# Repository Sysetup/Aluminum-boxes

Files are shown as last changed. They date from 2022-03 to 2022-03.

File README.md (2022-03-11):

```console
   ____             __             
  / __/_ _____ ___ / /___ _____ _/|
 _\ \/ // (_-</ -_) __/ // / _ > _<
/___/\_, /___/\__/\__/\_,_/ .__//  
    /___/                /_/       
> Systems development company.
```

- [Boxes.](#boxes)

# Boxes.

1. Boxes may be stacked with each other and join the internal space between them.
2. **Each box** shall have on its exterior a part that allows it to be assembled on any of its sides with another box of the same size or of other sizes, all the boxes shall have harmonious measurements so that they can be assembled together to form figures between them, they shall therefore have a part that allows them to be assembled with another box and can be secured in such a way that only with a key or by opening a padlock can they be disassembled.
3. **Each box** shall have perforations that allow it to be assembled on the floor, on a wall or on the ceiling. On the floor, walls or ceiling there shall be a part assembled with deep holes in the concrete that will allow the drawer(s) to be assembled and secured with padlocks, so that they cannot be moved by anyone but the owner of the padlocks.
4. **Each box** shall be capable of being locked with a key, key or padlock, so that it cannot be opened by anyone but the owner.
5. Aluminium material or (similar in weight, more economical and equal or superior in strength to aluminium).

----

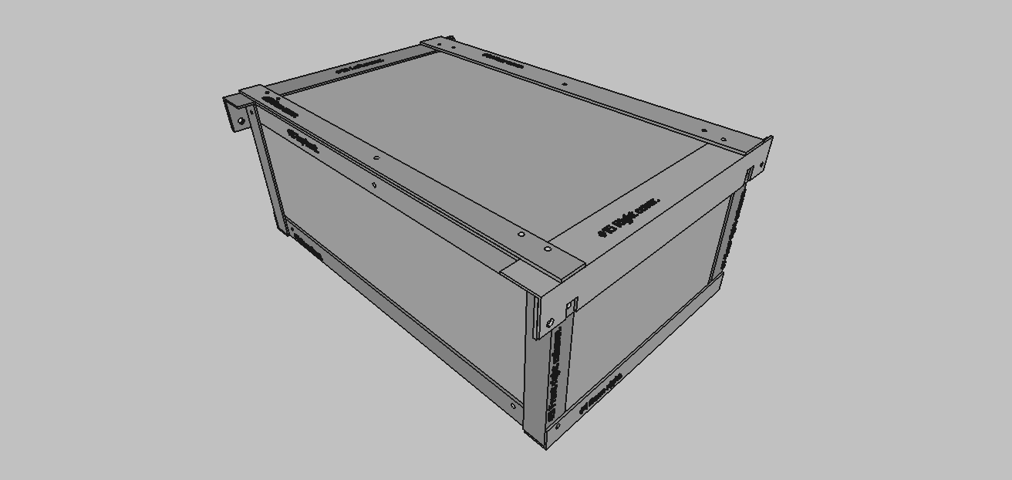
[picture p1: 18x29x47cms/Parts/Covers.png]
Covers


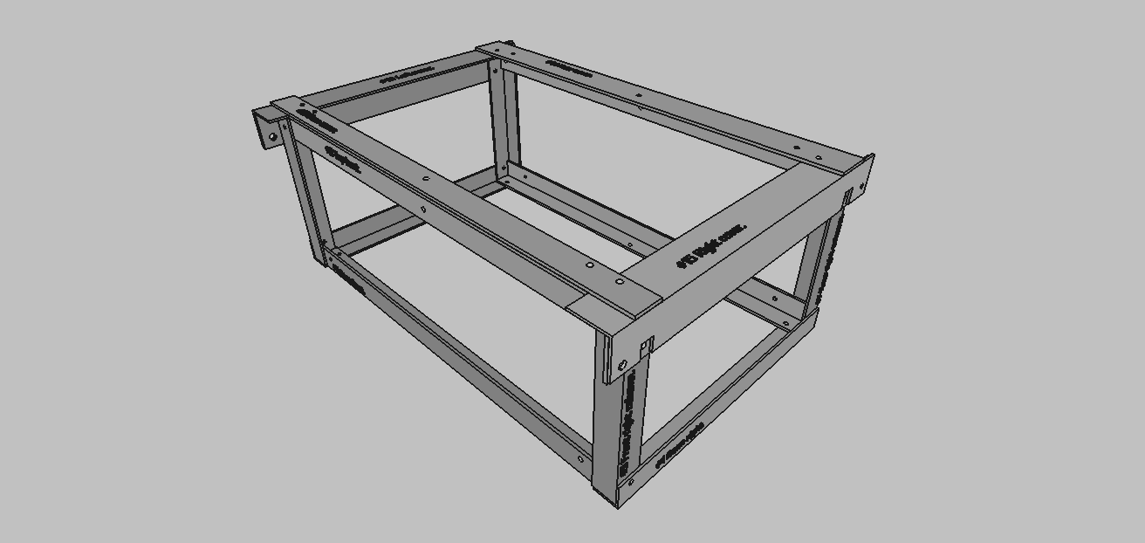
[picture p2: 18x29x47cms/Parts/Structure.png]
Structure


----

1. [Box: 180 x 290 x 470 mm.](./18x29x47cms/180x290x470mm.md)
2. [Box: 290 x 290 x 470 mm.](./29x29x47cms/290x290x470mm.md)
3. [Box: 290 x 470 x 470 mm.](./29x47x47cms/290x470x470mm.md)
4. [Box: 290 x 470 x 760 mm.](./29x47x76cms/290x470x760mm.md)

----

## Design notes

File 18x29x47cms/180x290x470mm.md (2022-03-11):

```console
   ____             __             
  / __/_ _____ ___ / /___ _____ _/|
 _\ \/ // (_-</ -_) __/ // / _ > _<
/___/\_, /___/\__/\__/\_,_/ .__//  
    /___/                /_/       
> Systems development company.
```

- [Box: 180 x 290 x 470 mm:](#box-180-x-290-x-470-mm)
  - [Box dimensions:](#box-dimensions)
  - [Parts:](#parts)
    - [Aluminium angles:](#aluminium-angles)
      - [Part no: A011.](#part-no-a011)
        - [Quantities:](#quantities)
      - [Reference: PA019.](#reference-pa019)
        - [Quantities:](#quantities-1)
    - [Aluminium plates:](#aluminium-plates)
      - [Part no: P18.](#part-no-p18)
        - [Quantities:](#quantities-2)
      - [Reference: PP030.](#reference-pp030)
        - [Quantities:](#quantities-3)
    - [Screws:](#screws)
    - [Nuts:](#nuts)
    - [Washers:](#washers)
    - [Cover:](#cover)
      - [Covering with carpet:](#covering-with-carpet)
      - [Covering measurements:](#covering-measurements)
      - [Cover with PP030 plates:](#cover-with-pp030-plates)

# Box: 180 x 290 x 470 mm:

## Box dimensions:

1. Box dimensions: 18 x 29 x 29 x 47 cms (180 x 290 x 470 mm), internally. Using fibonasi sequence measurements with seeds 1 and 3.

## Parts:

### Aluminium angles:

#### Part no: A011.
   
1. External width: 25.15 mm.
2. Internal width: 22,85 mm.
3. Calibre: 2.3 mm.

##### Quantities:

1. 2 * 470.00 mm --> Rear base length and front base length. [Parts #3 and #4] 
2. 2 * 300.94 mm --> Base widths.  [Parts #1 and #2] 3. 
3. 4 * 182.30 mm --> Rear and front columns. [(#5 and #6), (#7 and #8)].

Total angles A011: 2271.08 mm. **2.3 Metres.

#### Reference: PA019.
   
1. External width: 38.5 mm.
2. Internal width: 38,1 mm.
3. Calibre: 3.18 mm.

##### Quantities:

1. 2 * 342 mm --> Cover widths. [Parts #15 and #16] 

Total angles PA019: 683.8 mm. **70 Centimetres.

### Aluminium plates:

#### Part no: P18.

Width: 25,65 mm.
2. Gauge: 3.17 mm.

##### Quantities:
      
1. 2 * 470 mm --> Length top front and top rear. 470 mm. [#9 y #10]
2. 1 * 486,9 mm --> Length front top. [#13]
3. 2 * 410,20 mm--> Lid support bases. [#17 y #18]

Total plates P18: 2247.3 mm. 2.3 Meter ** 2.3 Meter ** 2.3 Meter ** 2.3 Meter ** 2.3 Meter

#### Reference: PP030.
   
Width 38.1 mm.
2. Gauge: 3.17.

##### Quantities:

1. 2 * 342 mm --> Width top right and top left. 642 mm. [#11 y #12]
2. 1 * 486,9 mm --> Length rear cover [#14].

Total plates PP030: 1128,9 mm. 1.2 Meters ** 1.2 Meters ** 1.2 Meters

### Screws:

1. 36 pcs. 4,8 mm diameter. 17 mm long thread. (4 of 8 mm) (The minimum that they must have to cover the thickness of 2 corners and a plate that are the 3 parts of the door that need more length. For the purchased ones you have to cut them) Head diameter 9 mm. 3 mm head height, 34 mm total length.

### Nuts:

1. 36 pcs. nuts with security. 10.9 mm diameter at longest end, 3.9 mm diameter inner hole, width (gauge) 6 mm.

### Washers:

1. 72 pcs.
2. 12.8 mm diameter, 5.5 mm hole, gauge 1 mm.

### Cover:

#### Covering with carpet:

1. Area: 0,55 mts² = cms²/10000 -> 0.5462 meters² ≃ 60 cms². Thickness: 3 mm. 
2. [Reference calculation](https://www.calculator.net/surface-area-calculator.html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)

#### Covering measurements:

1. Top cover: 441,00 mm x 272,00 mm x max: 3 mm.
2. Bottom cover: 460 mm x 282,00 mm x maximum: 3 mm.
3. Front cover: 462,00 mm x 167,00 mm x max. 3 mm.
4. Rear cover: 462,60 mm x 167,00 mm x max. 3 mm.
5. Right cover: 282,00 mm x 155,00 mm x maximum: 3 mm.
6. Left cover: 282.00 mm x 155.00 mm x max. 3 mm.

#### Cover with PP030 plates:

1. 7 x 486.9 mm. Top.
2. 4 x 470 mm. Front.
3. 3 x 470 mm. Rear.
4. 6 x 470 mm. Bottom.
5. 6 x 300 mm. Right and Left.

Total: 9175.3 mm. **9.2 metres** $9800 each metre.

----

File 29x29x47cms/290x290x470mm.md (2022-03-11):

```console
   ____             __             
  / __/_ _____ ___ / /___ _____ _/|
 _\ \/ // (_-</ -_) __/ // / _ > _<
/___/\_, /___/\__/\__/\_,_/ .__//  
    /___/                /_/       
> Systems development company.
```

- [Box: 290 x 290 x 470 mm.](#box-290-x-290-x-470-mm)
  - [Box dimensions:](#box-dimensions)
  - [Parts:](#parts)
    - [Aluminium angles:](#aluminium-angles)
      - [Part no: A011.](#part-no-a011)
        - [Quantities:](#quantities)
      - [Reference: PA019.](#reference-pa019)
        - [Quantities:](#quantities-1)
    - [Aluminium plates:](#aluminium-plates)
      - [Part no: P18.](#part-no-p18)
        - [Quantities:](#quantities-2)
      - [Reference: PP030.](#reference-pp030)
        - [Quantities:](#quantities-3)
    - [Screws:](#screws)
    - [Nuts:](#nuts)
    - [Washers:](#washers)
    - [Cover:](#cover)
      - [Covering with pin:](#covering-with-pin)
      - [Measurements coverings:](#measurements-coverings)

# Box: 290 x 290 x 470 mm.

## Box dimensions:

1. Box dimensions: 29 x 29 x 47 cms (290 x 290 x 470 mm), internally. Using fibonasi sequence measurements with seeds 1 and 3.

## Parts:

### Aluminium angles:

#### Part no: A011.
   
1. External width: 25.15 mm.
2. Internal width: 22,85 mm.
3. Calibre: 2.3 mm.

##### Quantities:

1. 2 * 470.00 mm --> Rear base length and front base length. [Parts #3 and #4] 
2. 2 * 300.94 mm --> Base widths.  [Parts #1 and #2] 3. 
3. 4 * 292.30 mm --> Rear and front columns. [(#5 and #6), (#7 and #8)].

Total angles A011: 2271.08 mm. **2.74 Metres.

#### Reference: PA019.
   
1. External width: 38.5 mm.
2. Internal width: 38,1 mm.
3. Calibre: 3.18 mm.

##### Quantities: 

1. 2 * 342 mm --> Cover widths. [Parts #15 and #16]

Total angles PA019: 683.8 mm. **70 Centimetres.

### Aluminium plates:

#### Part no: P18.

Width: 25,65 mm.
2. Gauge: 3.17 mm.

##### Quantities:
      
1. 2 * 470 mm --> Length top front and top rear. 470 mm. [#9 y #10] 
2. 1 * 486,9 mm --> Length front top. [#13]
3. 2 * 410,20 mm--> Lid support bases. [#17 y #18]

Total plates P18: 2247.3 mm. 2.3 Meter ** 2.3 Meter ** 2.3 Meter ** 2.3 Meter ** 2.3 Meter

#### Reference: PP030.
   
Width 38.1 mm.
2. Gauge: 3.17.

##### Quantities:

1. 2 * 342 mm --> Width top right and top left. 642 mm. [#11 y #12]
2. 1 * 486,9 mm --> Length rear cover [#14].

Total plates PP030: 1128,9 mm. 1.2 Meters ** 1.2 Meters ** 1.2 Meters

### Screws:

1. 27 pcs. 4,8 mm diameter. 17 mm long thread. (4 of 8 mm) (The minimum that they must have to cover the thickness of 2 corners and a plate that are the 3 parts of the door that need more length. For the purchased ones you have to cut them) Head diameter 9 mm. 3 mm head height, 34 mm total length.

### Nuts:

1. 27 pcs nuts with security. 10.9 mm diameter at longest end, 3.9 mm diameter inner hole, width (gauge) 6 mm.

### Washers:

1. 54 pcs.
2. 12.8 mm diameter, 5.5 mm hole, gauge 1 mm.

### Cover:

#### Covering with pin:

1. Area: 0.7134 meters² ≃ 72 cms². Thickness: 2mm.
2. [Calculation reference](https://www.calculator.net/surface-area-calculator.html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)

#### Measurements coverings:

1. Top cover: 441,00 mm x 272,00 mm x max: 3 mm.
2. Bottom cover: 460 mm x 282,00 mm x maximum: 3 mm.
3. Front cover: 462,00 mm x 273,00 mm x max. 3 mm.
4. Rear cover: 462,60 mm x 273,00 mm x max. 3 mm.
5. Right cover: 282,00 mm x 265,00 mm x maximum: 3 mm.
6. Left cover: 282,00 mm x 265,00 mm x max. 3 mm.

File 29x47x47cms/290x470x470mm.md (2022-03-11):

```console
   ____             __             
  / __/_ _____ ___ / /___ _____ _/|
 _\ \/ // (_-</ -_) __/ // / _ > _<
/___/\_, /___/\__/\__/\_,_/ .__//  
    /___/                /_/       
> Systems development company.
```

- [Box: 290 x 470 x 470 mm:](#box-290-x-470-x-470-mm)
  - [Box dimensions:](#box-dimensions)
  - [Parts:](#parts)
    - [Angles:](#angles)
      - [Reference: A15:](#reference-a15)
        - [Quantities:](#quantities)
      - [Reference: PA019:](#reference-pa019)
        - [Quantities:](#quantities-1)
    - [Plates:](#plates)
      - [Part no: PP030:](#part-no-pp030)
        - [Quantities:](#quantities-2)
    - [Covering:](#covering)
      - [Covering with carpet:](#covering-with-carpet)
      - [Cover measurements:](#cover-measurements)

# Box: 290 x 470 x 470 mm:

## Box dimensions:

1. Box dimensions: 29 x 47 x 47 cms (290 x 470 x 470 x 470 mm), internally. Using fibonasi sequence measurements with seeds 1 and 3.

## Parts:

### Angles:

#### Reference: A15:

1. External width: 31.9 mm.
2. Internal width: 28.9 mm.
3. Gauge: 3.1 mm.

##### Quantities:

1. 2 * 470 mm --> Rear base length and front base length. [Parts #3 and #4]
2. 2 * 482.4 mm --> Base widths.  [Parts #1 and #2] 3.
3. 4 * 293.10 mm --> Rear and front columns. [(#5 and #6), (#7 and #8)].

Total angles A015: 3077.2 mm. **3,1 Metres.

#### Reference: PA019:

1. External width: 38,5 mm.
2. Internal width: 35,1 mm.
3. Calibre: 3.18 mm.

##### Quantities: 

1. 2 * 550 --> Cap widths. [Parts #15 and #16]

Total angles PA019: 1100 mm. **1.3 Meters

### Plates:

#### Part no: PP030:
   
1. Width 38,1 mm.
2. Calibre: 3.17.

##### Quantities:

1. 2 * 550 mm --> Width top right and top left. 1004.8 mm. [#11 y #12] 
2. 2 * 568 mm --> Length top front and rear. 1556 mm. [#13 y #14]
3. 2 * 470 mm --> Length top front and top rear. 1520 mm. [#9 y #10]

Total PP030 plates: 3176 mm. **3.3 Metres.

### Covering:

#### Covering with carpet:

1. Area: 0.55 mts² = cms²/10000 -> 0.5462 meters² ≃ 60 cms². Thickness: 3 mm. 
2. [Reference calculation](https://www.calculator.net/surface-area-calculator.html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)

#### Cover measurements:

1. Top cover: 440 mm x 440 mm x max: 3 mm.
2. Bottom cover: 445 mm x 445 mm x maximum: 3 mm.
3. Front cover: 465 mm x 280 mm x max.: 3 mm.
4. Rear cover: 465 mm x 265 mm x max.: 3 mm.
5. Right cover: 465 mm x 275 mm x max. 3 mm.
6. Left cover: 465 mm x 275 mm x max. 3 mm.

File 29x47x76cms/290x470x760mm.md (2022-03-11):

```console
   ____             __             
  / __/_ _____ ___ / /___ _____ _/|
 _\ \/ // (_-</ -_) __/ // / _ > _<
/___/\_, /___/\__/\__/\_,_/ .__//  
    /___/                /_/       
> Systems development company.
```

- [Box: 290 x 470 x 760 mm:](#box-290-x-470-x-760-mm)
  - [Box dimensions:](#box-dimensions)
  - [Parts:](#parts)
    - [Angles:](#angles)
      - [Reference: A15:](#reference-a15)
        - [Quantities:](#quantities)
      - [Reference: PA019:](#reference-pa019)
        - [Quantities:](#quantities-1)
    - [Plates:](#plates)
      - [Part no: PP030:](#part-no-pp030)
        - [Quantities:](#quantities-2)
    - [Screws:](#screws)
    - [Nuts:](#nuts)
    - [Washers:](#washers)
    - [Cover:](#cover)
      - [Covering with carpet:](#covering-with-carpet)
      - [Measurements coverings:](#measurements-coverings)

# Box: 290 x 470 x 760 mm:

## Box dimensions:

1. Box Dimensions: 29 x 47 x 76 cms (290 x 470 x 760 mm), internally. Using fibonasi sequence measurements with seeds 1 and 3.

## Parts:

### Angles:

#### Reference: A15:

1. External width: 31.9 mm.
2. Internal width: 28.9 mm.
3. Gauge: 3.1 mm.

##### Quantities:

1. 2 * 760 mm --> Rear base length and front base length. [Parts #3 and #4]
2. 2 * 482.4 mm --> Base widths.  [Parts #1 and #2] 3.
3. 4 * 293.10 mm --> Rear and front columns. [(#5 and #6), (#7 and #8)].

Total angles A015: 3658 mm. **4 Metres.

#### Reference: PA019:

1. External width: 38,5 mm.
2. Internal width: 35,1 mm.
3. Calibre: 3.18 mm.

##### Quantities: 

1. 2 * 550 --> Cap widths. [Parts #15 and #16]

Total angles PA019: 1100 mm. **1.2 Meters

### Plates:

#### Part no: PP030:
   
1. Width 38,1 mm.
2. Calibre: 3.17.

##### Quantities:

1. 2 * 550 mm --> Width top right and top left. 1004.8 mm. [#11 y #12]
2. 2 * 785 mm --> Length top front and rear. 1556 mm. [#13 y #14]
3. 2 * 760 mm --> Length top front and top rear. 1520 mm. [#9 y #10]

Total PP030 plates: 4190 mm. **4.2 Metres.

### Screws:

1. 42 pcs. 4,8 mm diameter. 17 mm long thread. (4 of 8 mm) (The minimum that they must have to cover the thickness of 2 corners and a plate that are the 3 parts of the door that need more length. For the purchased ones you have to cut them) Head diameter 9 mm. 3 mm head height.
2. Assembling the box physically, you can see that the screws can be 16 mm long on the thread alone.

### Nuts:

1. 42 units of nuts with security. 10.9 mm diameter at the longest end, 3.9 mm diameter inner hole, width (gauge) 6 mm.

### Washers:

1. 84 pcs.
2. 12.8 mm diameter, 5.5 mm hole, gauge 1 mm.

### Cover:

#### Covering with carpet:

1. Area: 1.4278 meters² ≃ 1.50 cms².  Thickness: 3 mm.
2. [Reference calculation](https://www.calculator.net/surface-area-calculator.html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)

#### Measurements coverings:

3. Top cover: 755 mm x 440 mm x max: 3 mm.
4. Bottom cover: 745 mm x 445 mm x max.: 3 mm.
5. Front cover: 745 mm x 280 mm x maximum: 3 mm.
6. Rear cover: 745 mm x 265 mm x maximum: 3 mm.
7. Right cover: 465 mm x 275 mm x max. 3 mm.
8. Left cover: 465 mm x 275 mm x max. 3 mm.

----

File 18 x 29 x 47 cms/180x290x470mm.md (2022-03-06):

```console
   ____             __             
  / __/_ _____ ___ / /___ _____ _/|
 _\ \/ // (_-</ -_) __/ // / _ > _<
/___/\_, /___/\__/\__/\_,_/ .__//  
    /___/                /_/       
> Systems development company.
```

- [Box: 180 x 290 x 470 mm:](#box-180-x-290-x-470-mm)
  - [Cajas a construir:](#cajas-a-construir)
  - [Medidas de la caja:](#medidas-de-la-caja)
  - [Partes:](#partes)
    - [Angulos de aluminio:](#angulos-de-aluminio)
      - [Referencia: A011.](#referencia-a011)
        - [Cantidades:](#cantidades)
      - [Referencia: PA019.](#referencia-pa019)
        - [Cantidades:](#cantidades-1)
    - [Platinas de aluminio:](#platinas-de-aluminio)
      - [Referencia: P18.](#referencia-p18)
        - [Cantidades:](#cantidades-2)
      - [Referencia: PP030.](#referencia-pp030)
        - [Cantidades:](#cantidades-3)
    - [Tornillos:](#tornillos)
    - [Tuercas:](#tuercas)
    - [Arandelas:](#arandelas)
    - [Cubrimiento:](#cubrimiento)
      - [Cubrimiento con alfajor:](#cubrimiento-con-alfajor)
      - [Medidas cubrimientos:](#medidas-cubrimientos)
      - [Cubrimiento con platinas PP030:](#cubrimiento-con-platinas-pp030)
  - [Costos totales:](#costos-totales)
    - [Costos angulos:](#costos-angulos)
    - [Costos platinas:](#costos-platinas)
    - [Costos tornillos:](#costos-tornillos)
    - [Costos tuercas:](#costos-tuercas)
    - [Costos arandelas:](#costos-arandelas)
    - [Costos cubiertas:](#costos-cubiertas)
      - [Cubierta con alfajor:](#cubierta-con-alfajor)
      - [Cubierta con lamina perforada:](#cubierta-con-lamina-perforada)
      - [Cubierta con maya:](#cubierta-con-maya)
    - [COSTO TOTAL: $120026 con alfajor.](#costo-total-120026-con-alfajor)
  - [Repositori:](#repositori)

# Box: 180 x 290 x 470 mm:

## Cajas a construir:

1. [x] Para elementos solares.
2. [x] Para papeleria.
3. [ ] Para alacena, comidas, cafe, leches, chocolate.
4. [ ] Para libros.

## Medidas de la caja:

1. Medidas de la caja: 18 x 29 x 47 cms (180 x 290 x 470 mm), internamente. Usando medidas de la secuencia fibonasi con semillas 1 y 3.

## Partes:

### Angulos de aluminio:

#### Referencia: A011.
   
1. Ancho externo: 25,15 mm.
2. Ancho interno: 22,85 mm.
3. Calibre: 2,3 mm.

##### Cantidades:

1. 2 * 470,00 mm  --> Largo base trasera y largo base frontal. [Partes #3 y #4] 
2. 2 * 300,94 mm  --> Anchos de la base.  [Partes #1 y #2] 
3. 4 * 182,30 mm  --> Columnas traseras y frontales. [(#5 y #6), (#7 y #8)]

Total angulos A011: 2271,08 mm. **2.3 Metros.**

#### Referencia: PA019.
   
1. Ancho externo: 38,5 mm.
2. Ancho interno: 38,1 mm.
3. Calibre: 3,18 mm.

##### Cantidades: 

1. 2 * 342 mm --> Anchos de la tapa. [Partes #15 y #16] 

Total angulos PA019: 683,8 mm. **70 Centimetros.**

### Platinas de aluminio:

#### Referencia: P18.

1. Ancho: 25,65 mm.
2. Calibre: 3,17 mm.

##### Cantidades:
      
1. 2 * 470 mm  --> Largo top front and top rear. 470 mm. [#9 y #10] 
2. 1 * 486,9 mm --> Largo tapa front. [#13]
3. 2 * 410,20 mm--> Bases de apoyo tapa. [#17 y #18]

Total platinas P18: 2247,3 mm. **2,3 Metro.**

#### Referencia: PP030.
   
1. Ancho 38,1 mm.
2. Calibre: 3,17.

##### Cantidades:

1. 2 * 342 mm  --> Ancho top right and top left. 642 mm. [#11 y #12]
2. 1 * 486,9 mm --> Largo tapa rear [#14]

Total platinas PP030: 1128,9 mm. **1,2 Metros.**

### Tornillos:

1. 27 unidades. 4,8 mm de diametro. 17 mm de largo en la rosca. (4 de 8 mm) (Lo minimo que deben tener para cubrir el grosor de 2 angulos y una platina que son las 3 partes de la puerta que mas largo necesitan. Para los comprados hay que cortarlos) Diametro de la cabeza 9 mm. 3 mm alto de la cabeza, 34 mm de largo total.

### Tuercas:

1. 27 unidades de tuercas con seguridad. 10,9 mm de diametro en el extremo mas largo, 3,9 mm de diametro orificio interno, ancho (calibre) 6 mm.

### Arandelas:

1. 54 unidades.
2. 12,8 mm de diametro, orificio de 5,5 mm, calibre 1 mm.

### Cubrimiento:

#### Cubrimiento con alfajor:

1. Area: 0,55 mts² = cms²/10000 -> 0.5462 meters² ≃ 60 cms². Grosor: 3 mm. 
2. [Referencia calculo](https://www.calculator.net/surface-area-calculator.html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)

#### Medidas cubrimientos:

1. Top cover: 441,00 mm x 272,00 mm x maximo: 3 mm.
2. Bottom cover: 460 mm x 282,00 mm x maximo: 3 mm.
3. Front cover: 462,00 mm x 167,00 mm x maximo: 3 mm.
4. Rear cover: 462,60 mm x 167,00 mm x maximo: 3 mm.
5. Right cover: 282,00 mm x 155,00 mm x maximo: 3 mm.
6. Left cover: 282,00 mm x 155,00 mm x maximo: 3 mm.

#### Cubrimiento con platinas PP030:

1. 7 x 486,9 mm. Top.
2. 4 x 470 mm. Front.
3. 3 x 470 mm. Rear.
4. 6 x 470 mm. Bottom.
5. 6 x 300 mm. Right y Left.

Total: 9175,3 mm. **9,2 metros** $9800 cada metro.

## Costos totales:

### Costos angulos:

1. Cada metro de angulo A011: $8403 x 2.3 Metros = $19327.
2. Cada metro de angulo PA019: $17643 x 70 Centimetros = $12350.

Sub total: $31677.

### Costos platinas:

1. Cada metro de platina P18: $3445 x 2,3 metro = $7923.5
2. Cada metro de platina PP030: $9785 x 1,2 Metros = $11742

Sub total: $16909.5
 
### Costos tornillos:

1. 27 Tornillos: Cada tornillo: $450 x 27 = $12150.

### Costos tuercas:

1. 27 Tuercas: Cada tuerca: $65 x 27 = $1755.

### Costos arandelas:

1. 54 Arandelas: Cada arandela: $87 x 54 = $4698.

### Costos cubiertas:

#### Cubierta con alfajor:

1. Cada 1² = $50000 
2. Cada 1² $88.000 x 1mm, $135.000 x 1,5mm [Reference](www.elpalaciodelaluminio.com)

#### Cubierta con lamina perforada:

1. Cada 1² = $

#### Cubierta con maya:

1. Cada 1² = $

### COSTO TOTAL: $120026 con alfajor.

## Repositori:

1. https://github.com/Sysetup/aluminum-boxes

----

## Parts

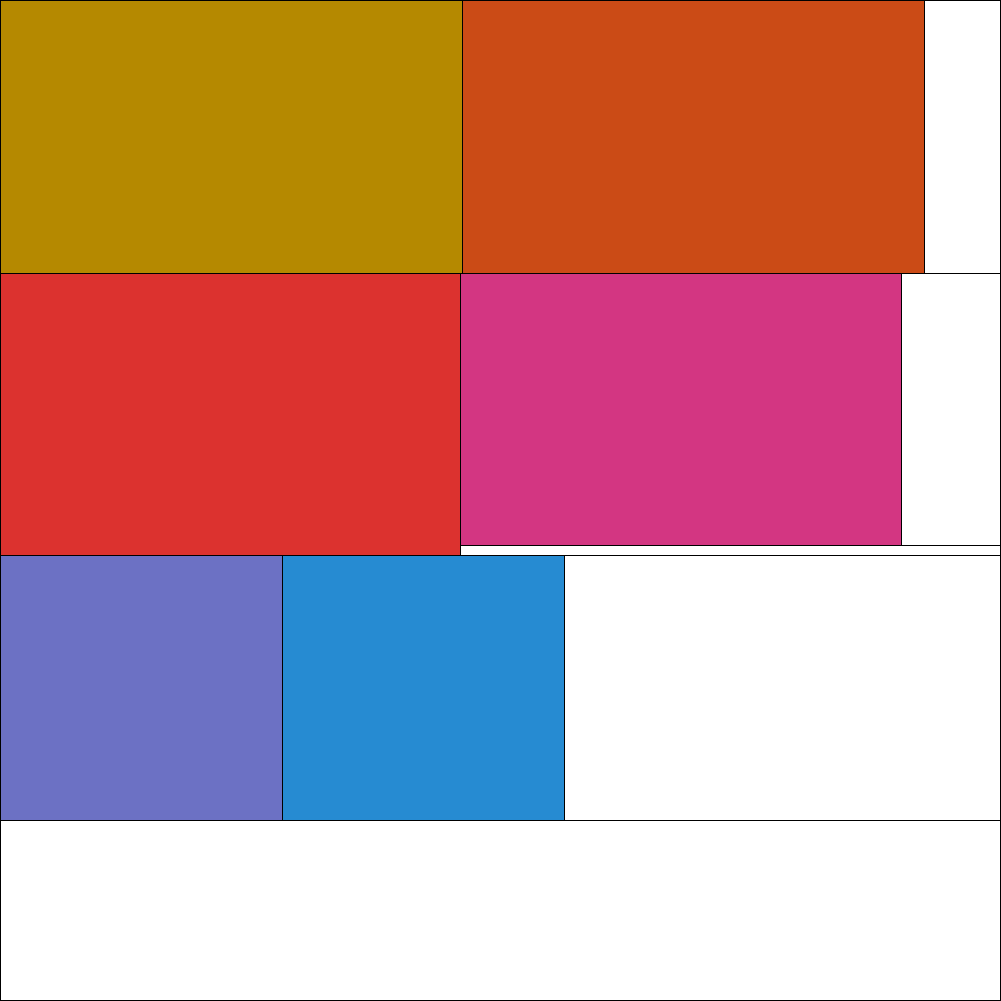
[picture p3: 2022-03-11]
29x29x47cms/Parts/Covers/download (1).png

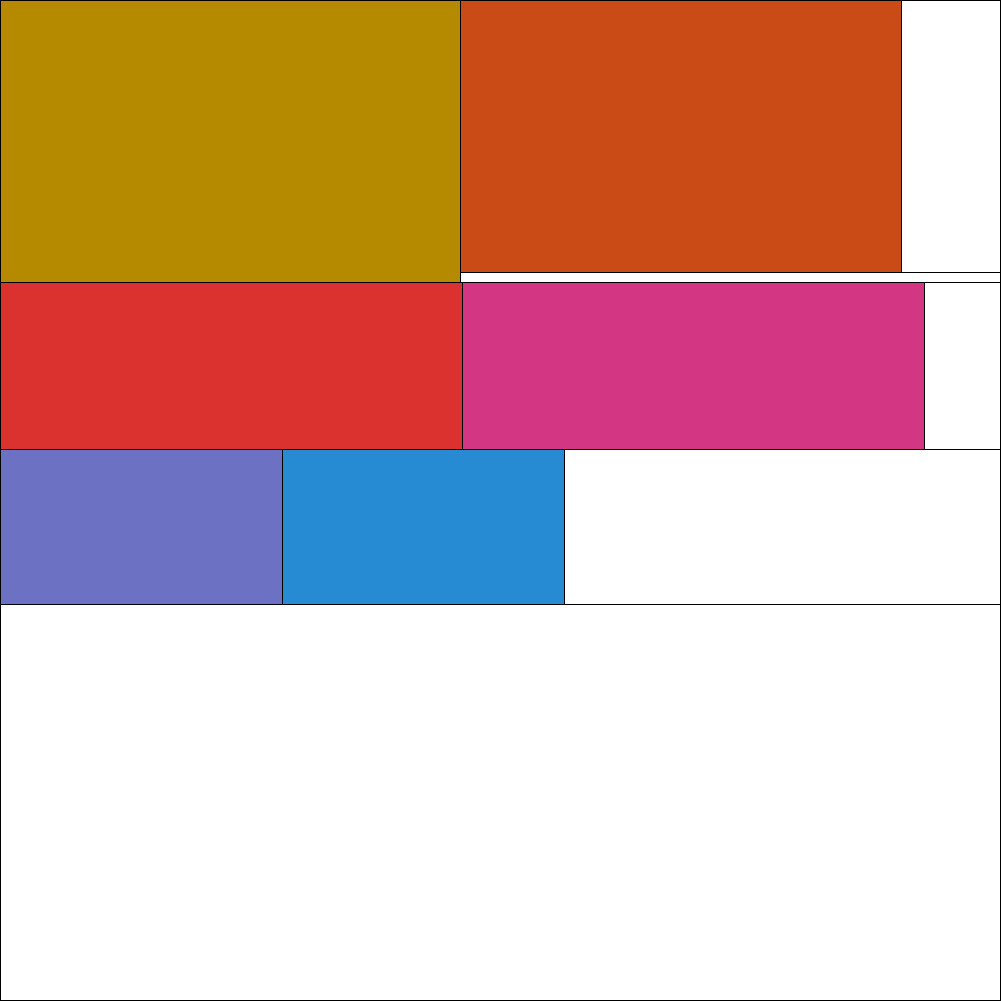
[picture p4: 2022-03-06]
18x29x47cms/Parts/Covers/download.png

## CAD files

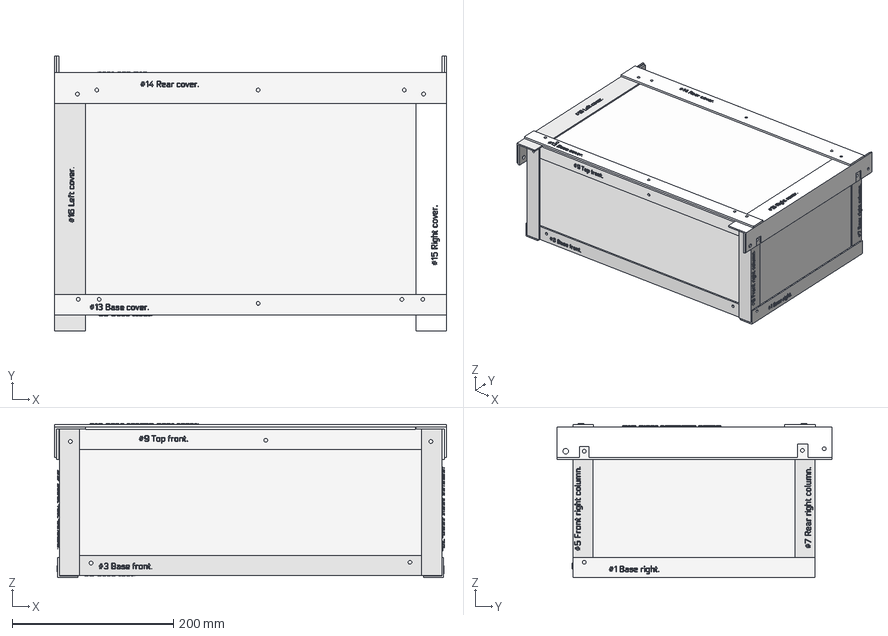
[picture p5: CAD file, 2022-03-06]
18 x 29 x 47 cms/Box.FCStd
486.9 x 342.0 x 191.5 mm

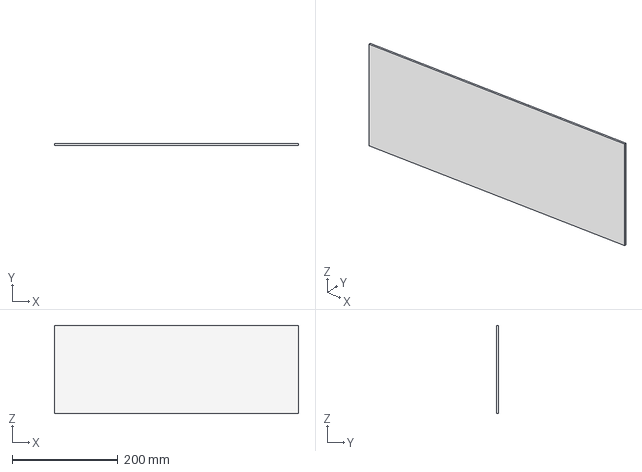
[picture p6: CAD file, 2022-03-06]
18 x 29 x 47 cms/Parts/Covers/Front cover.FCStd
462.0 x 3.00 x 167.0 mm

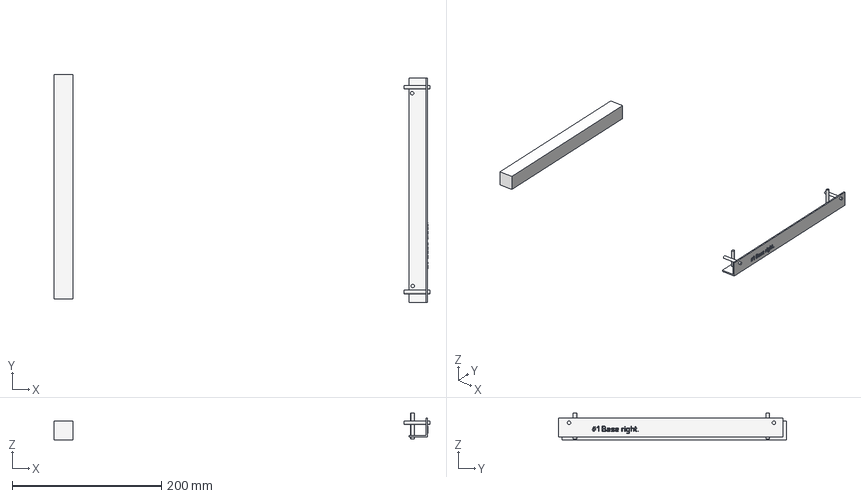
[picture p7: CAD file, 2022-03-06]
18 x 29 x 47 cms/Parts/Plates and angles/#1 y #2/#1 Base right.FCStd
503.9 x 305.6 x 36.0 mm

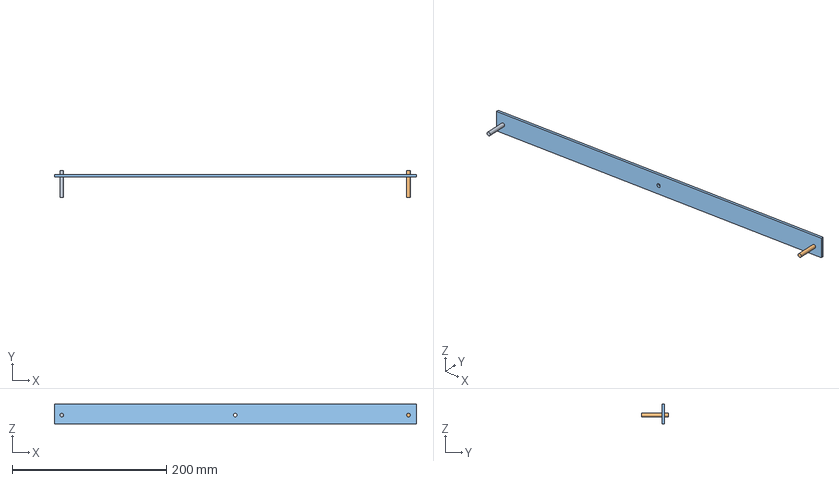
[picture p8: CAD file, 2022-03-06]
18 x 29 x 47 cms/Parts/Plates and angles/#10/#10 Top rear.FCStd
470.0 x 35.0 x 25.6 mm

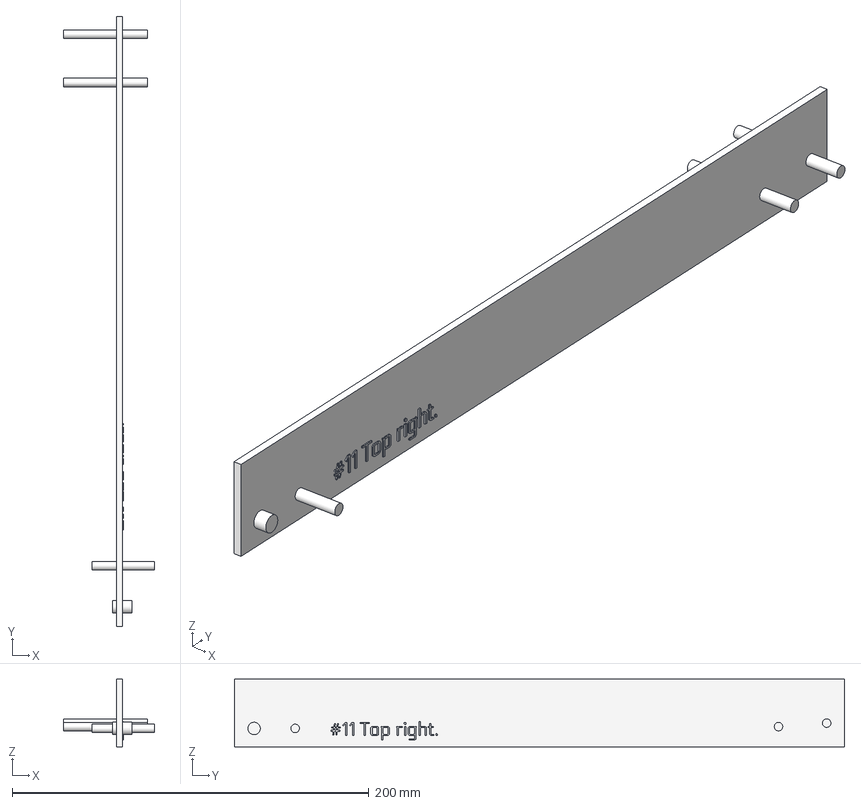
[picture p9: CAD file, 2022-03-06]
18 x 29 x 47 cms/Parts/Plates and angles/#11 y #12/#11 Top right.FCStd
51.0 x 342.0 x 38.1 mm

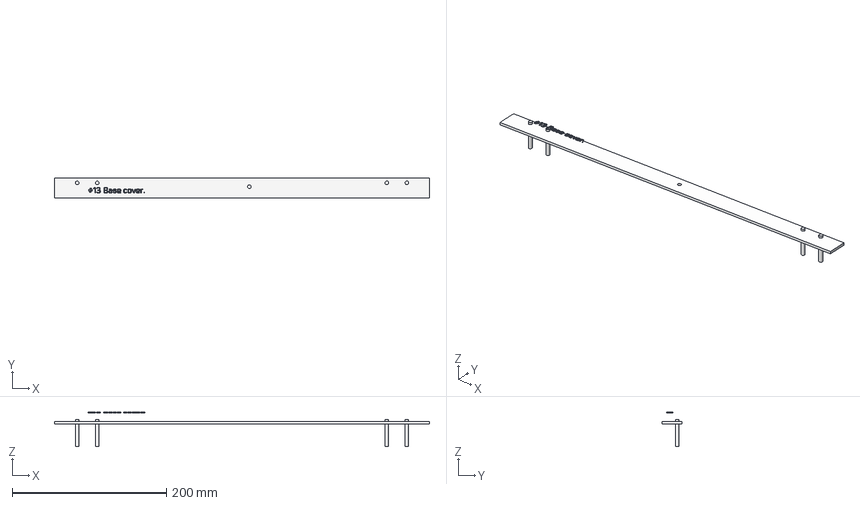
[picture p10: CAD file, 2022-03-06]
18 x 29 x 47 cms/Parts/Plates and angles/#13/#13 Base cover.FCStd
486.9 x 25.6 x 44.5 mm

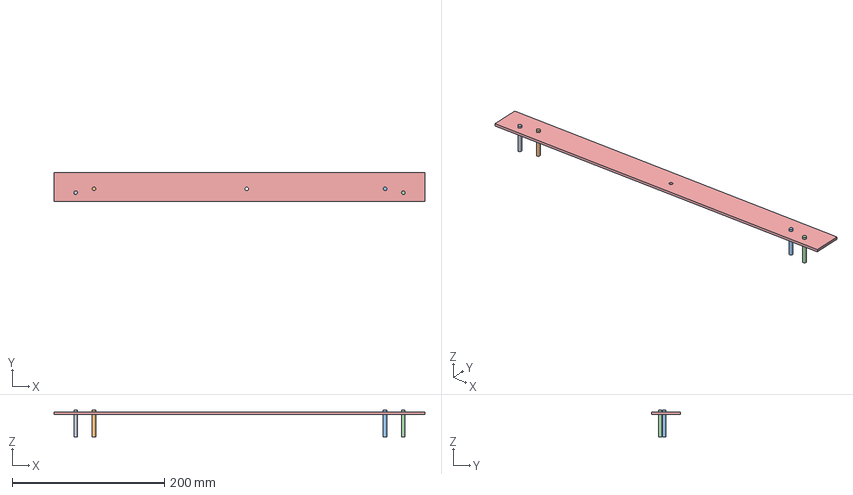
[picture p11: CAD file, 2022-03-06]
18 x 29 x 47 cms/Parts/Plates and angles/#14/#14 Rear cover.FCStd
486.9 x 38.1 x 35.0 mm

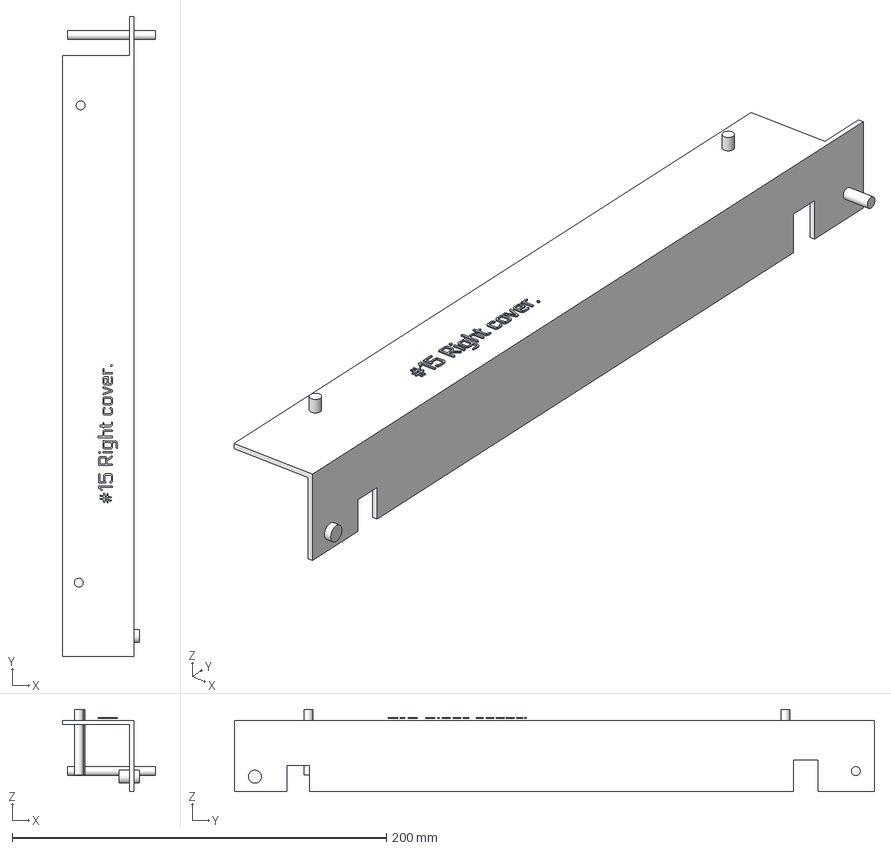
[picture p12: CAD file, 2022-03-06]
18 x 29 x 47 cms/Parts/Plates and angles/#15 y #16/#15 Right cover.FCStd
49.7 x 341.9 x 44.0 mm

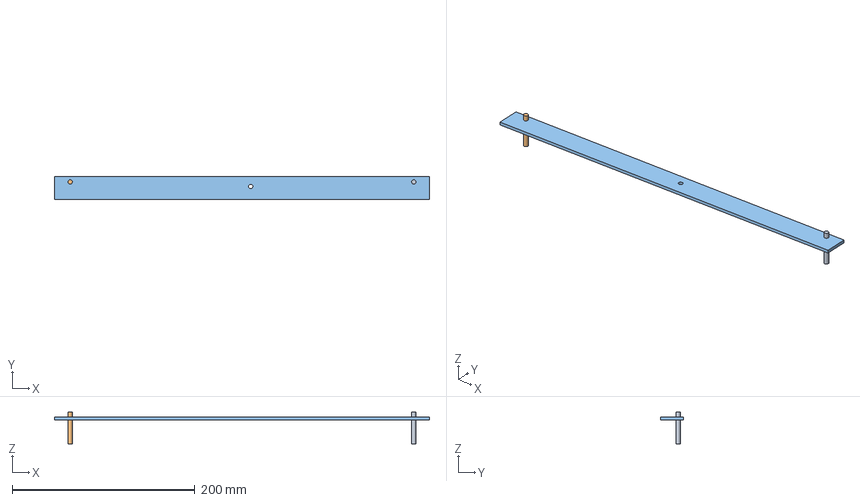
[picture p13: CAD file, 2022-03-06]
18 x 29 x 47 cms/Parts/Plates and angles/#17/#17 Base front fit.FCStd
410.4 x 25.6 x 35.0 mm

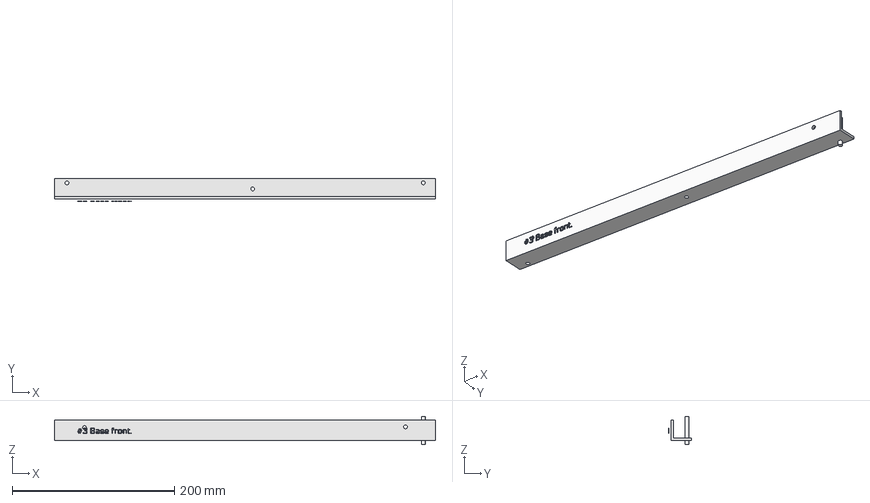
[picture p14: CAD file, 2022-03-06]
18 x 29 x 47 cms/Parts/Plates and angles/#3/#3 Base front.FCStd
470.0 x 28.4 x 35.0 mm

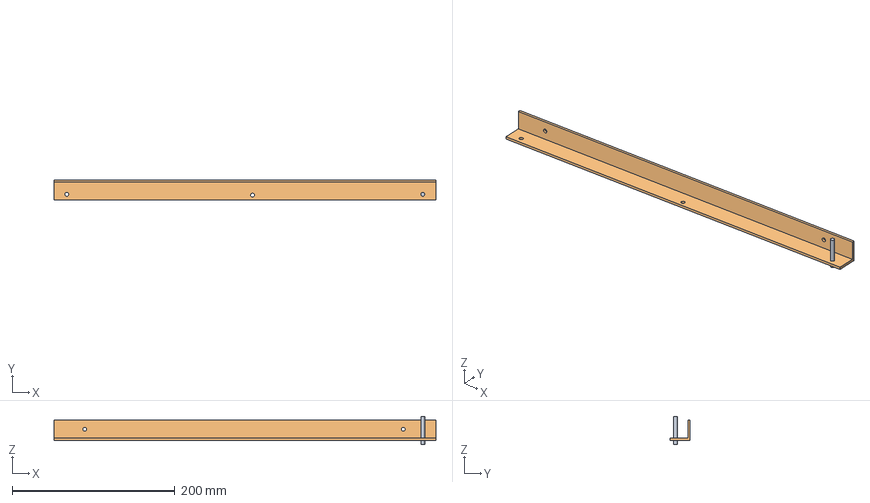
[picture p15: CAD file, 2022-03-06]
18 x 29 x 47 cms/Parts/Plates and angles/#4/#4 Base rear.FCStd
470.0 x 25.2 x 35.0 mm

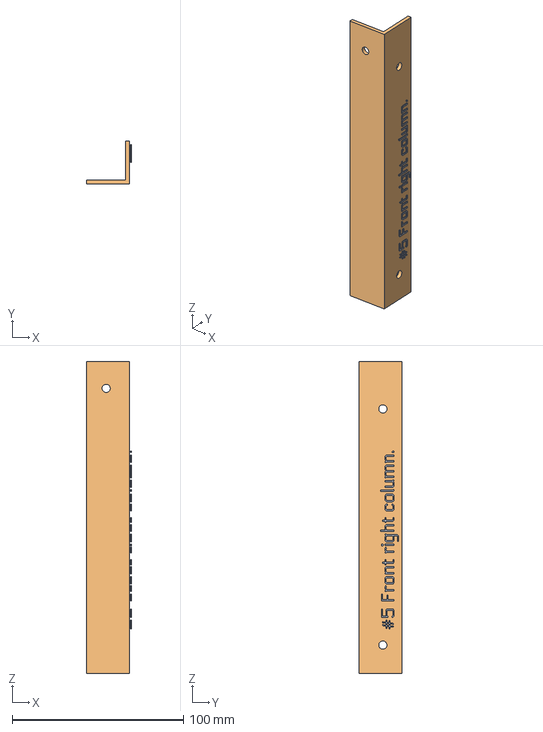
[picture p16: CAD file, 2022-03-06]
18 x 29 x 47 cms/Parts/Plates and angles/#5 y #6/#5 Front right column.FCStd
26.2 x 25.2 x 182.3 mm

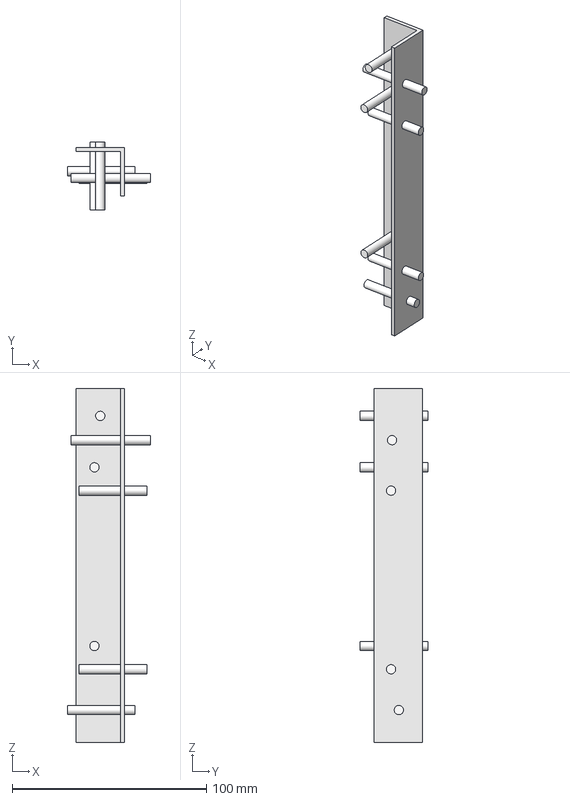
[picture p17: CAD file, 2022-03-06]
18 x 29 x 47 cms/Parts/Plates and angles/#7 y #8/#7 Rear right column.FCStd
43.0 x 35.0 x 182.3 mm

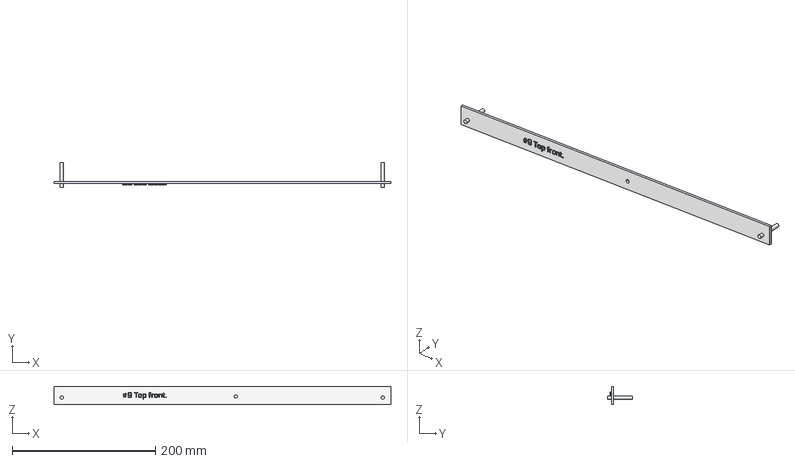
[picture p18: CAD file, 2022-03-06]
18 x 29 x 47 cms/Parts/Plates and angles/#9/#9 Top front.FCStd
470.0 x 35.0 x 25.6 mm

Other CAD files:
18 x 29 x 47 cms/Parts/Plates and angles/#18/#18 Base rear fit.FCStd
18 x 29 x 47 cms/Parts/Plates and angles/Connector.FCStd
18x29x47cms/Parts/Covers/Bottom cover.FCStd
18 x 29 x 47 cms/Parts/Covers/Alfajor.FCStd
18 x 29 x 47 cms/Parts/Covers/Bottom cover.FCStd
18 x 29 x 47 cms/Parts/Covers/Left cover.FCStd
18 x 29 x 47 cms/Parts/Covers/Rear cover.FCStd
18 x 29 x 47 cms/Parts/Covers/Right cover.FCStd
18 x 29 x 47 cms/Parts/Covers/Top cover.FCStd
18x29x47cms/Parts/Covers/Alfajor.FCStd
18x29x47cms/Parts/Covers/Left cover.FCStd
18x29x47cms/Parts/Covers/Rear cover.FCStd
18x29x47cms/Parts/Covers/Right cover.FCStd
18x29x47cms/Parts/Covers/Top cover.FCStd
18x29x47cms/Parts/Plates and angles/#18/#18 Base rear fit.FCStd
18x29x47cms/Parts/Plates and angles/Connector.FCStd
29x29x47cms/Parts/Covers/#17 Front cover.FCStd
29x29x47cms/Parts/Covers/#18 Top cover.FCStd
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

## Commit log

2021-12-25 Init files.
    [#1 Base right.FCStd, #11 Top right.FCStd, #13 Base cover.FCStd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]
2021-12-25 Sorting files.
    [01 Base right.FCStd, 02 Base left.FCStd, 03 Base front.FCStd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]
2021-12-29 Updated measures.
    [With plate PP030.FCStd]
2021-12-31 Holes update.
    [#1 Base right.FCStd, #3 Base front.FCStd, #5 Front right column.FCStd]
2022-01-12 Box update.
    [#1 Base right.FCStd, #10 Top rear.FCStd, #11 Top right.FCStd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]
2022-01-28 New boxes added.
    [#1 Base right.FCStd, #10 Top rear.FCStd, #11 Top right.FCStd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]
2022-02-05 Data updated.
    [Box.FCStd, Top cover.FCStd]
2022-02-12 Setting connectors.
    [#1 Base right.FCStd, #15 Right cover.FCStd, #5 Front right column.FCStd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]
2022-02-14 Tidy files.
    [#1 Base right.FCStd, #10 Top rear.FCStd, #11 Top right.FCStd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]
2022-02-21 Covers updated.
    [#1 Base right.FCStd, #10 Top rear.FCStd, #11 Top right.FCStd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]
2022-03-06 Cover fixes.
    [#1 Base right.FCStd, #10 Top rear.FCStd, #11 Top right.FCStd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]
2022-03-07 Real box.
    [#1 Base right.FCStd, #10 Top rear.FCStd, #11 Top right.FCStd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]
2022-03-11 Tidying up files.
    [#1 Base right.FCStd, #10 Top rear.FCStd, #11 Top right.FCStd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]
